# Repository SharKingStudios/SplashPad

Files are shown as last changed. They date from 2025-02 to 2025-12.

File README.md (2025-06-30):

<p align="center">
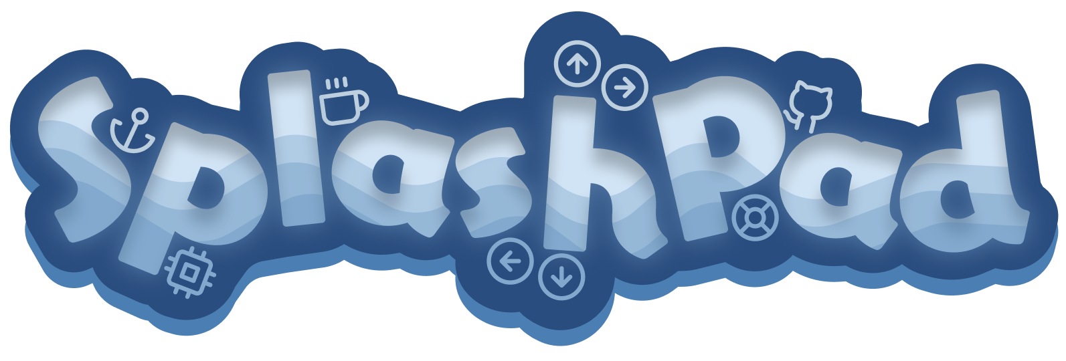
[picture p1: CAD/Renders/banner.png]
Banner
  
</p>

# SplashPad – Because You Deserve More Buttons  

### A Tiny, Glowing, Feature-Packed Macropad for Maximum Efficiency™  

*(Or just a cool way to press "Play" on your music.)*  

---

## Renders 
*Visuals because everyone loves eye candy.*

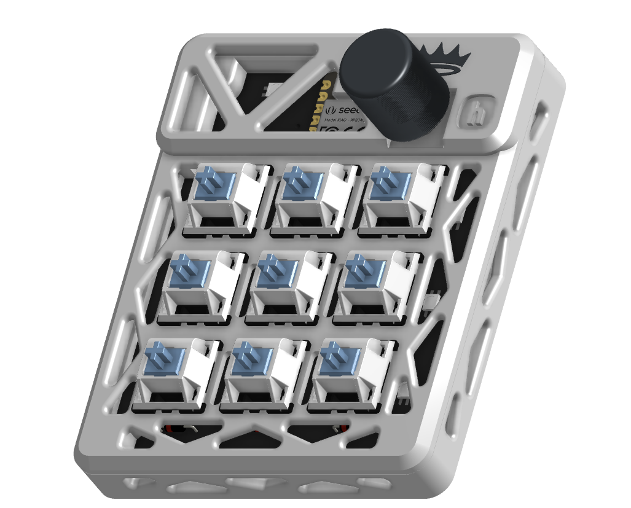
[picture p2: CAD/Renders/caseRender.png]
Case Render

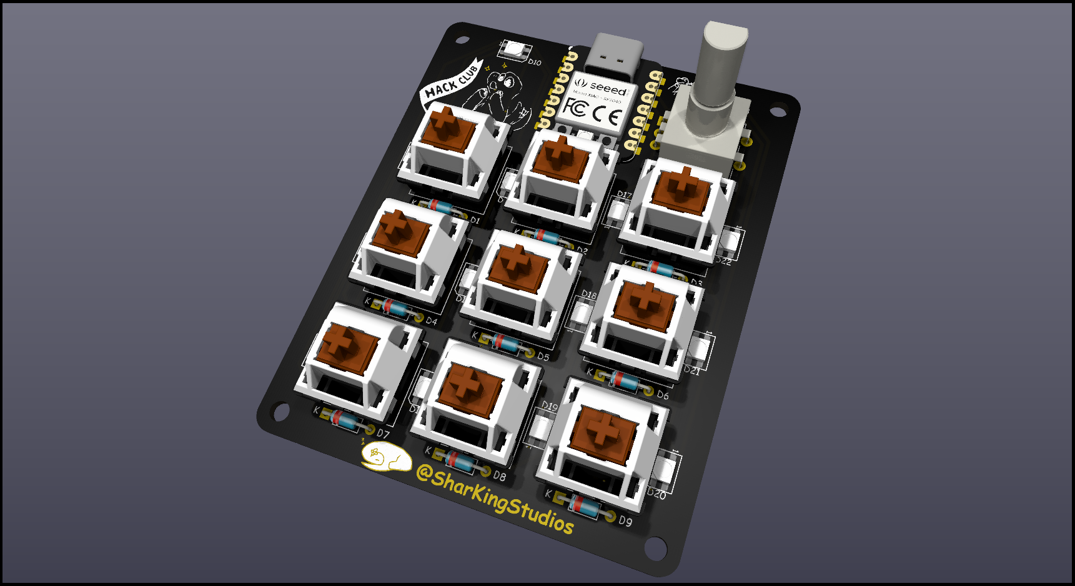
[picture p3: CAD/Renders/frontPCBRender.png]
Front PCB Render

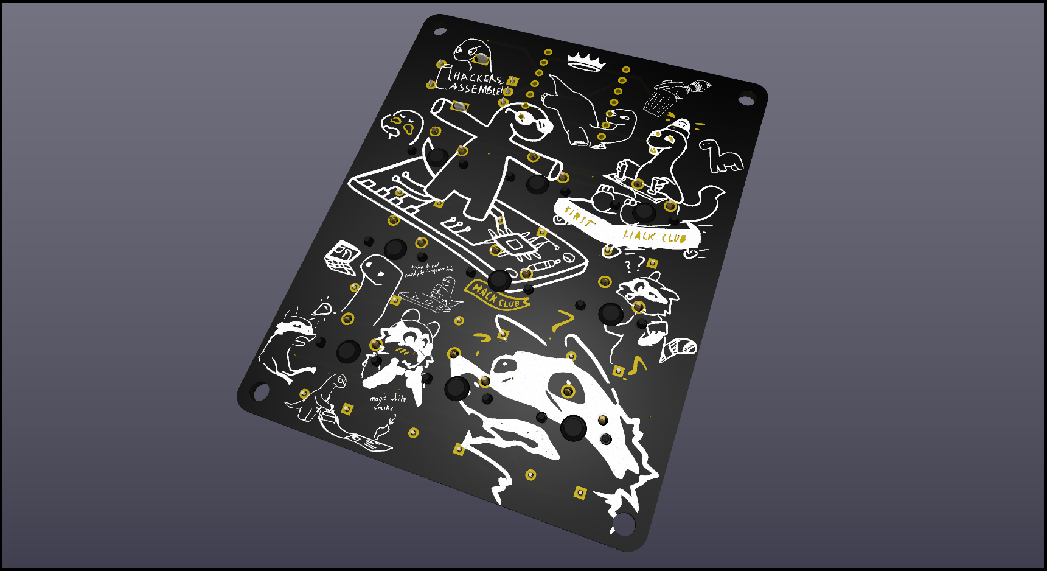
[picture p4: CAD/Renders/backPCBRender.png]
Back PCB Render

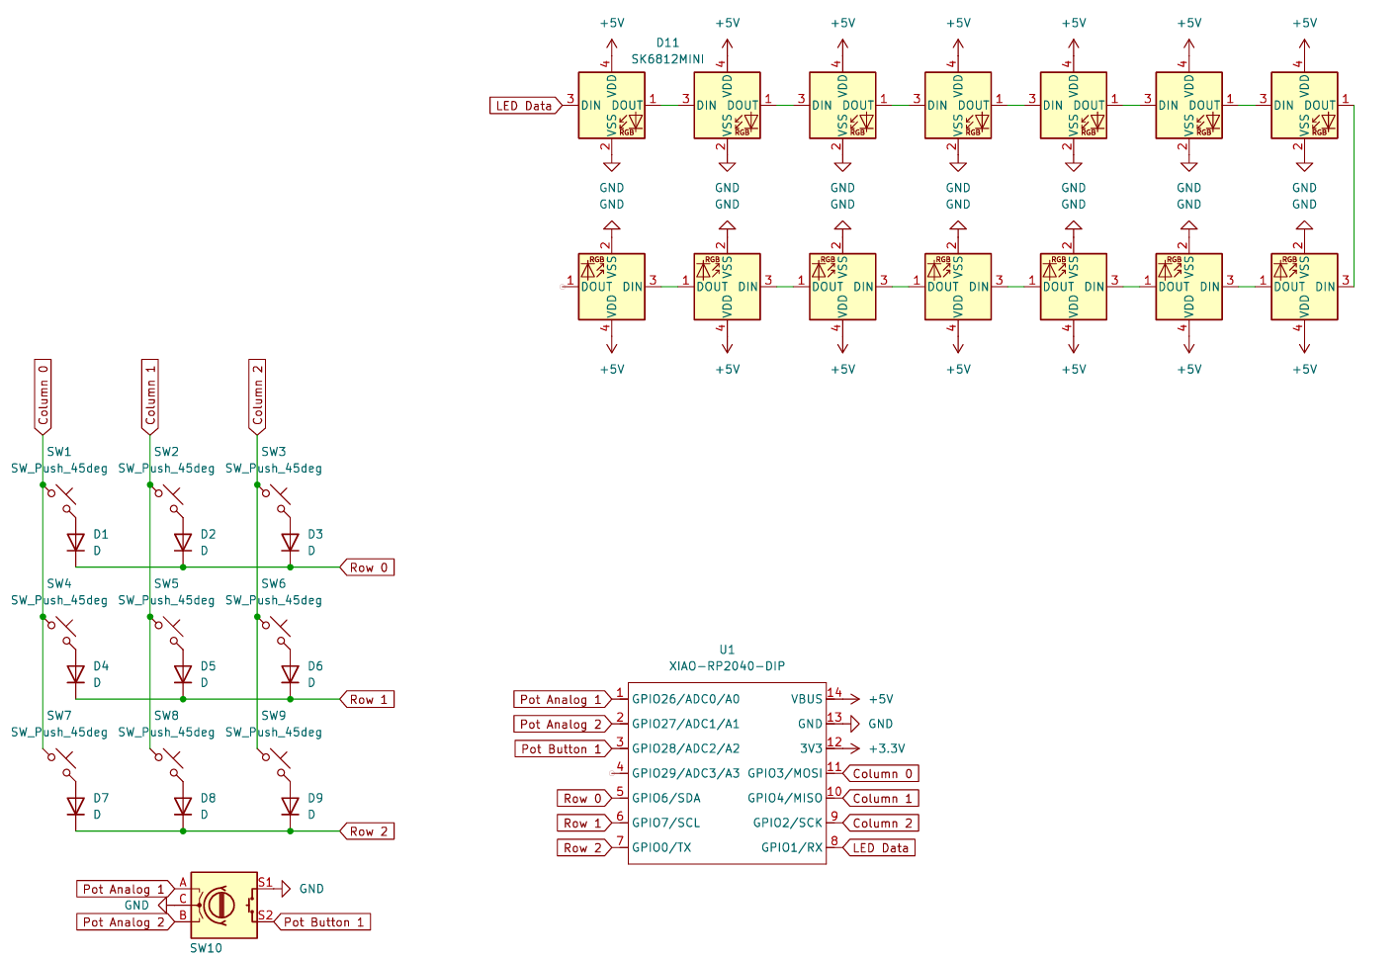
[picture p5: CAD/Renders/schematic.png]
Schematic Picture

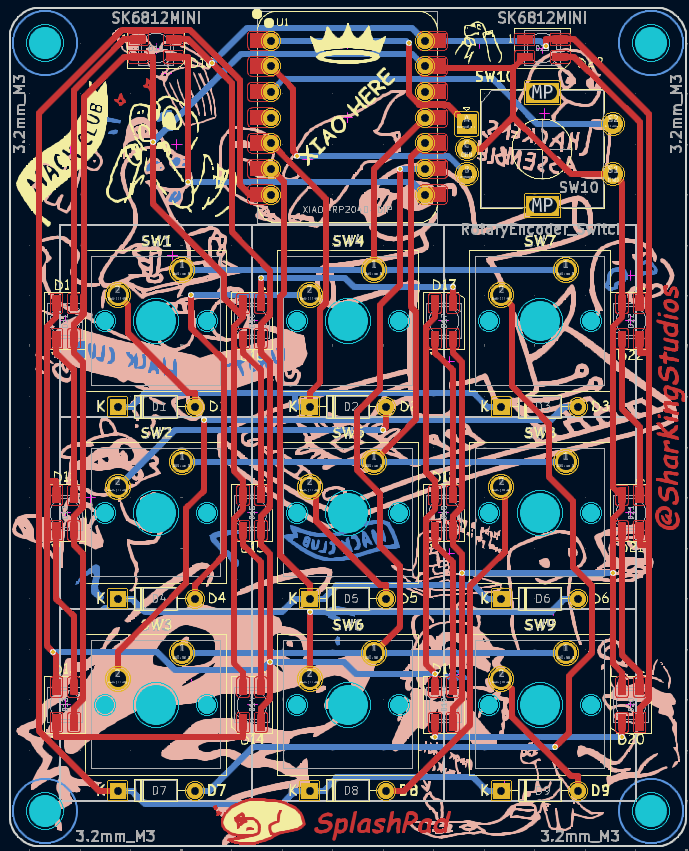
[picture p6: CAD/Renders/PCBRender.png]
PCB Design Picture


---
## BOM
All the bits and pieces needed can be found **[here](/BOM.md)**.

---

## What is this?  
It’s a **custom macropad** built with the **Seeed Studio XIAO RP2040**, **KMK firmware**, and **way too many LEDs**. Whether you’re gaming, editing, coding, or just pressing random buttons for fun, this thing’s got you covered.

### Features:
- **3x3 Matrix** – Nine glorious keys to map to whatever your heart desires.
- **Rotary Encoder** – Twist for volume, scroll, or secret hacker functions.
- **Clickable Encoder Button** – Because sometimes, twisting isn’t enough.
- **14 SK6812 Mini LEDs** – Way too many for a macropad this size. But hey, ✨blinkenlights✨.
- **Multiple LED Modes** – Solid, Rainbow, Wave, and Grid Fade, for when you need that cyberpunk aesthetic.
- **KMK Firmware** – Python-powered and open-source, because we like freedom.

---

## How It Works:
This macropad runs **KMK**, which means you get:
- **Custom Keymaps** – Map macros, media keys, or even full-blown scripts.
- **Dynamic Layers** – More functions per button? Yes, please.
- **LED Control** – Pulsing blue? Rainbow waves? Subtle grid fade? Pick your poison.
- **Rotary Encoder Support** – Spin for volume, brightness, scrolling, or **whatever**.

---

## Default Keymap (For the Lazy):
*(Change it if you want, I'm not your boss.)*

### **3x3 Button Layout:**
| Row | Key 1  | Key 2 | Key 3 |
|---|---|---|---|
| **1** | Rewind | Play/Pause | Fast Forward |
| **2** | Media  | Calculator | Cmd+R (Refresh) |
| **3** | Left | Right | Cmd+L (Lock) |

### **Rotary Encoder:**
- **Left Turn** → Volume Down
- **Right Turn** → Volume Up
- **Press Button** → Cycle LED modes

---

## How to Use:  
1. **Flash KMK** onto your XIAO RP2040. *(If you don’t know how, Google it.)*
2. **Drop `kb.py` and `main.py`** onto your board.
3. **Plug it in.** Watch the lights do their thing.
4. **Press buttons.** Turn the knob. Make magic happen.

---

## LED Modes:
Because a macropad without RGB is just a fancy calculator.

- **Solid Mode** – A slow, pulsing blue (totally not just lazy coding).
- **Rainbow Mode** – Taste the colors.
- **Wave Mode** – Water flow effect because vibes.
- **Grid Fade Mode** – Simulates sunlight through water. Or something poetic like that.

*(Press the encoder button to switch between them.)*

---

## Why?
I built this macropad for [Hackpad](https://hackpad.hackclub.com/)—an awesome Hack Club YSWS project run by [Alex Ren](https://github.com/qcoral). With a the (hopeful) funding provided by the project, I wanted to create something that’s as practical as it is playful. Whether you're coding, gaming, or just jamming to your favorite tunes, this macropad is my way of saying:

#### why settle for ordinary when you can hack something extraordinary?

## The Biggest Challenge:
I wanted to use nice thick wires for my PCB (0.6mm) and routing all of these took quite a bit of effort. I think the time spent was definitely worth it, as the routing looks *awesome*.

---

## Future Plans (Maybe):  
- OLED Screen? 🤔  
- Bluetooth support? (If I hate myself enough to deal with that.)
- More layers? (How many is too many? Asking for a friend.)
- MIDI support? (Why not turn this into a DJ controller?)

---

## Contribute  
Want to make it better? Open a PR, suggest a feature, or just yell at me on GitHub.

---

## Disclaimer  
This project is 100% free, open-source, and powered by **vibes**. If it breaks, explodes, or opens a black hole, **that’s on you.**

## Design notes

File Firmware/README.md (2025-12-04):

# KMK Firmware – SplashPad

### The Brains Behind My Macropad

This folder contains the **KMK firmware** for my **SplashPad**.

---

## What's over here? 
- **`kb.py`** – Defines the hardware setup: key matrix, rotary encoder, LED setup, and pin assignments.
- **`main.py`** – The actual firmware logic: key mappings, rotary encoder functions, LED effects, and main loop.

---

## Default Keymap  
| Row | Key 1  | Key 2 | Key 3 |
|---|---|---|---|
| **1** | Rewind | Play/Pause  | Fast Forward |
| **2** | Media  | Eject Media | Enter |
| **3** | Left | Right | Cmd |

- **Rotary Encoder:**  
  - **Left** → Volume Down
  - **Right** → Volume Up
  - **Press** → Cycle LED Modes

---

## LED Modes  
- **Solid Mode** – A slow pulsing blue glow.
- **Rainbow Mode** – Cycling RGB for that *gamer aesthetic*.
- **Wave Mode** – Water flow effect (because vibes).
- **Grid Fade Mode** – A subtle pulsing effect inspired by sunlight through water.

*(Press the encoder button to switch modes.)*

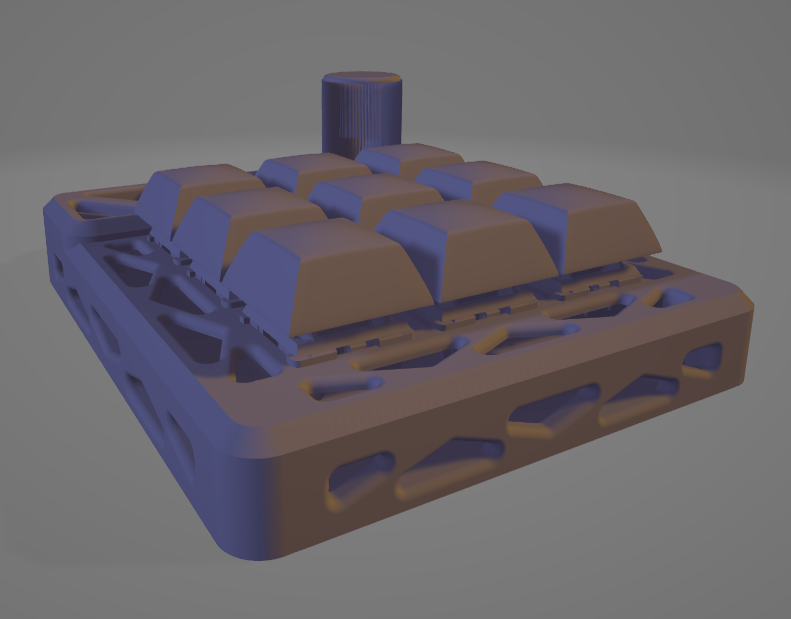
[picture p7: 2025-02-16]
CAD/Renders/darkPurpleRender.png

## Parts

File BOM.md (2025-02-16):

# SplashPad - Bill of Materials

Welcome to the **Bill of Materials (BOM)** – the sacred scroll of **everything** needed for my SplashPad. 

*(Because nothing’s worse than realizing you forgot the screws after your parts arrive.)* 

| **Component** | **Qty** |
|---|---|
| **XIAO RP2040** | 1 |
| **SK6812 Mini LEDs** | 14 |
| **Rotary Encoder** | 1 |
| **Cherry MX Switches** | 9 |
| **PCB** | 1 |
| **Diodes (1N4148)** | 9 |
| **M3x8 Bolt** | 4 |

Others:

| **Component** | **Qty** |
|---|---|
| **1U Keycaps** | 9 |
| **KMK Firmware** | 1 |
| **PCB** | 1 |
| [**Case Top.stl**](/CAD/STL/SplashPad%20Case%20-%20Case%20Top.stl) | 1 |
| [**Case Bottom.stl**](/CAD/STL/SplashPad%20Case%20-%20Case%20Bottom.stl) | 1 |
| **Knob.stl** | 1 |

### Notes:
It would be awesome to have the crown parts printed in black!
I can print the knob.
I am buying the M3x8 Bolts.

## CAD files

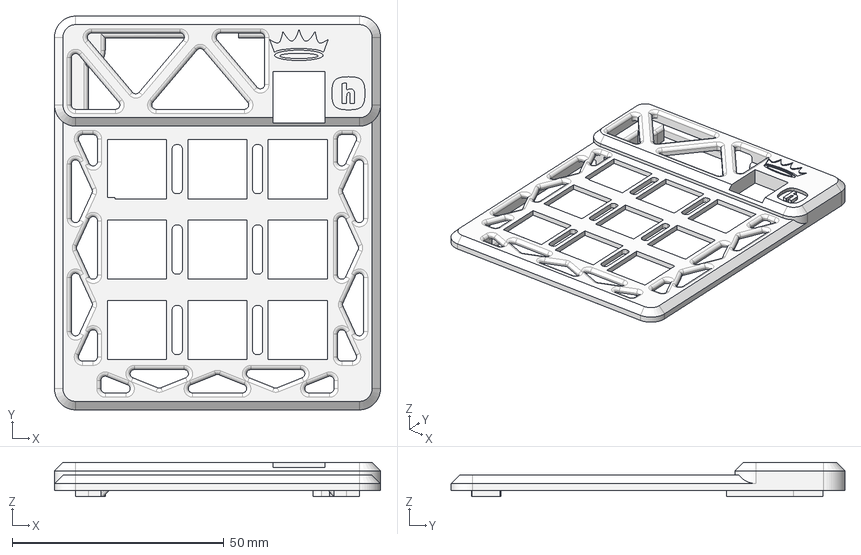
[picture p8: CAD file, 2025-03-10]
CAD/SplashPad Case - Case Top.step
77.0 x 93.0 x 8.09 mm

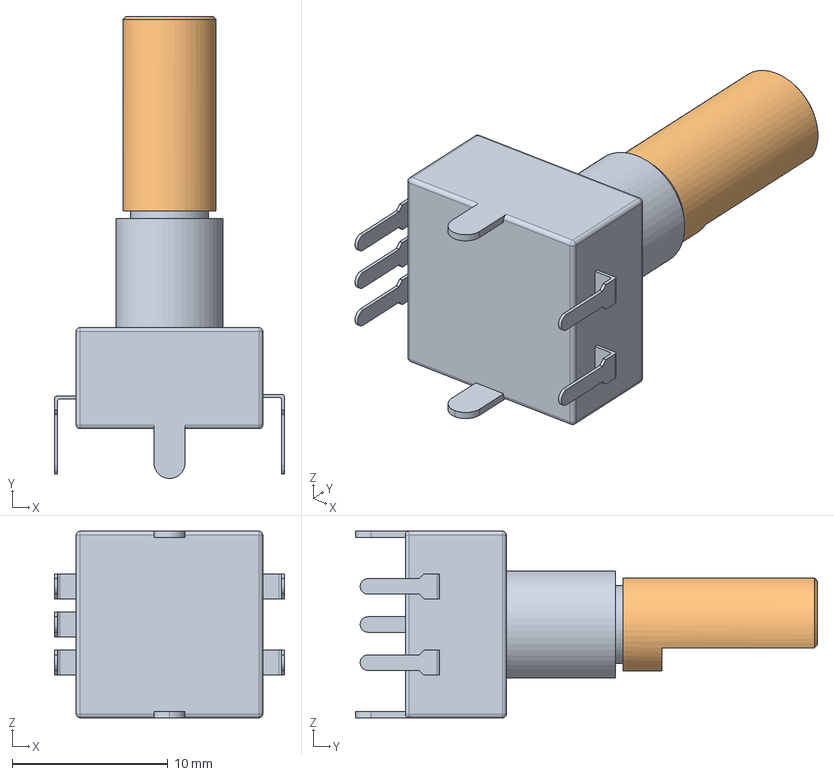
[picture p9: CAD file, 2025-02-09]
PCB/3D Models/RotaryEncoder_Alps_EC11E-Switch_Vertical_H20mm.step
14.8 x 29.7 x 12.0 mm

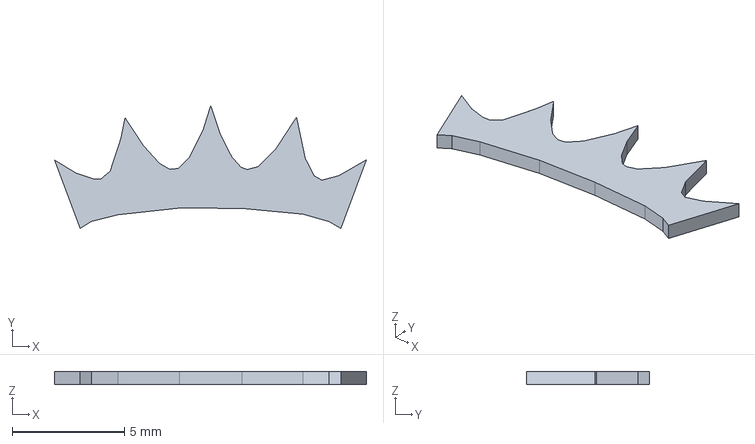
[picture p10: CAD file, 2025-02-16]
Production/SplashPad Case - Crown 2.step
13.9 x 5.47 x 0.6 mm

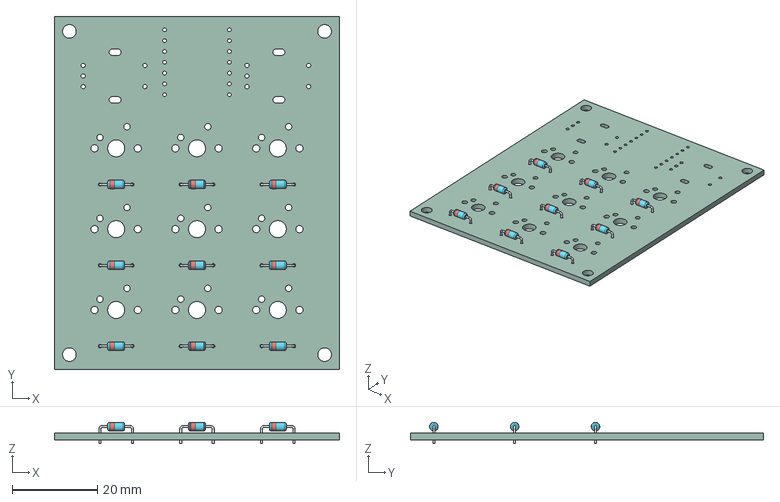
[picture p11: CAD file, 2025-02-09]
SplashPad.step
67.0 x 83.0 x 5.01 mm
D_DO-35_SOD27_P7.62mm_Horizontal x 9
SplashPad_PCB

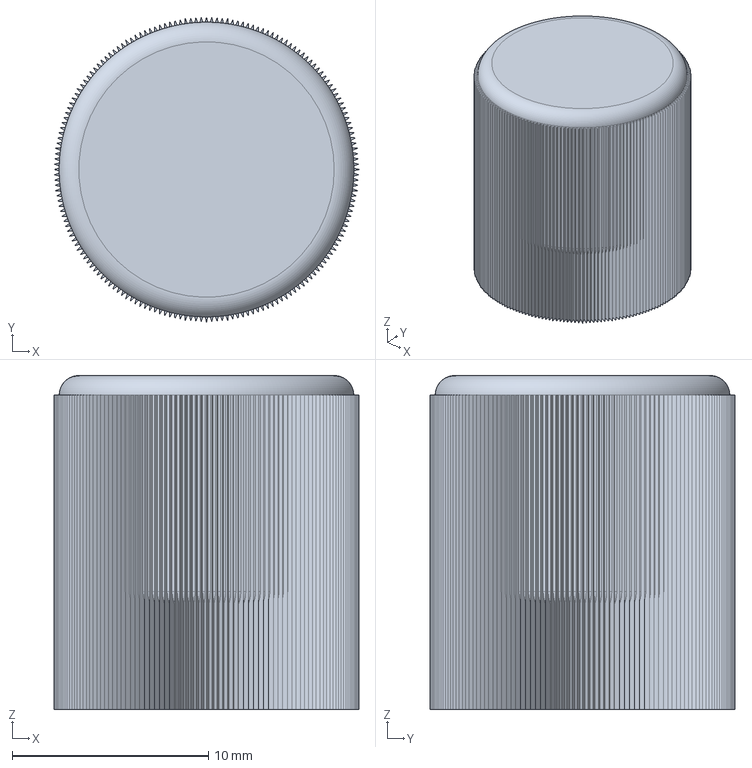
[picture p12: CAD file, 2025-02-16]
CAD/SplashPad Case - Knob.step
15.5 x 15.5 x 17.0 mm

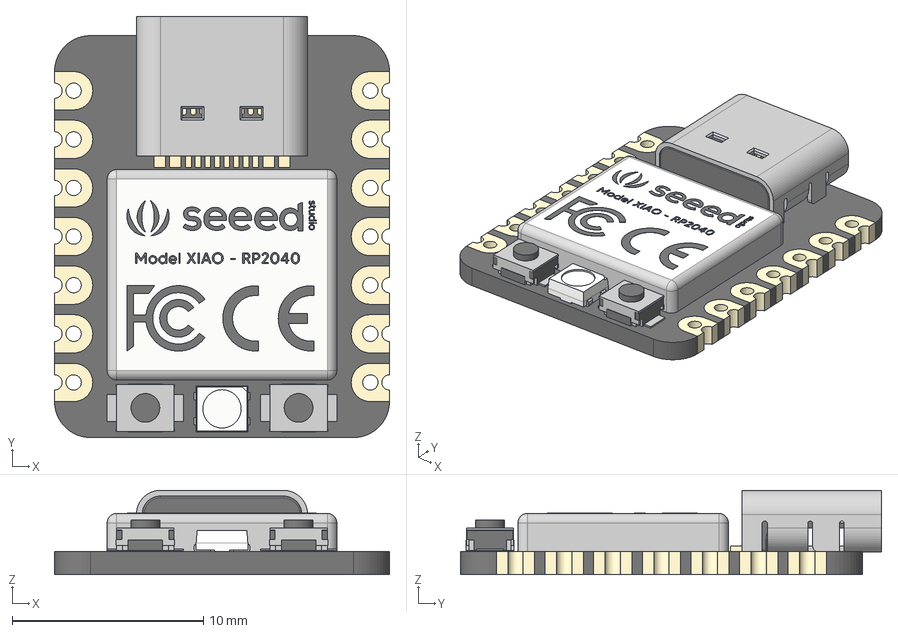
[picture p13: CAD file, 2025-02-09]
PCB/3D Models/Seeed_Studio_XIAO_RP2040_v26.step
17.5 x 22.0 x 4.40 mm
type-c v2
smd_button v3
DOUT
DIN
VSS
VDD
smd_button v3(Mirror)

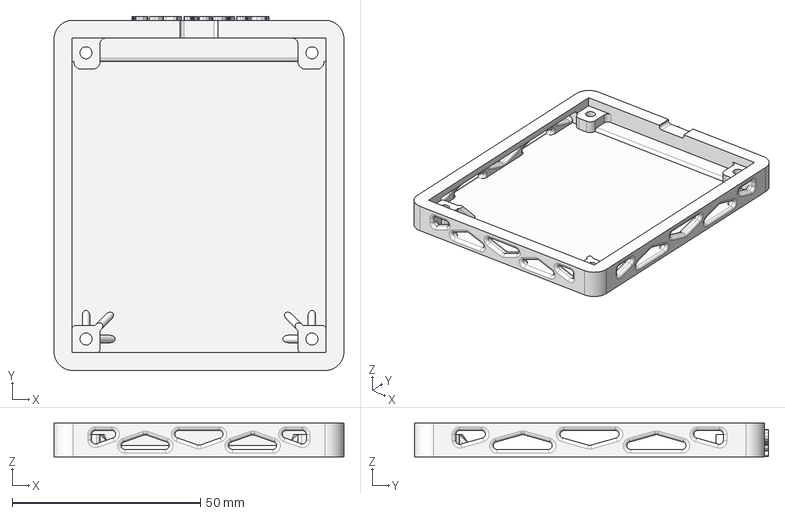
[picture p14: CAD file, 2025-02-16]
CAD/SplashPad Case - Case Bottom.step
77.0 x 94.0 x 9.00 mm

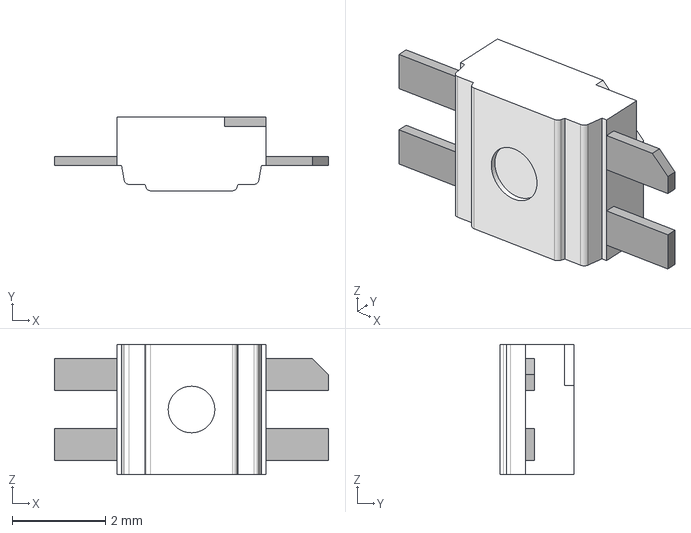
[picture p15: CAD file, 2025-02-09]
PCB/3D Models/SK6812MINI-E.step
5.88 x 1.58 x 2.80 mm

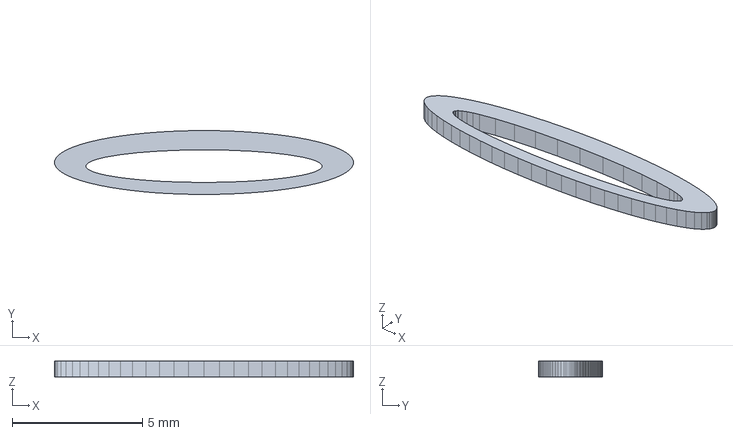
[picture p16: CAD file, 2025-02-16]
Production/SplashPad Case - Crown 1.step
11.5 x 2.45 x 0.6 mm

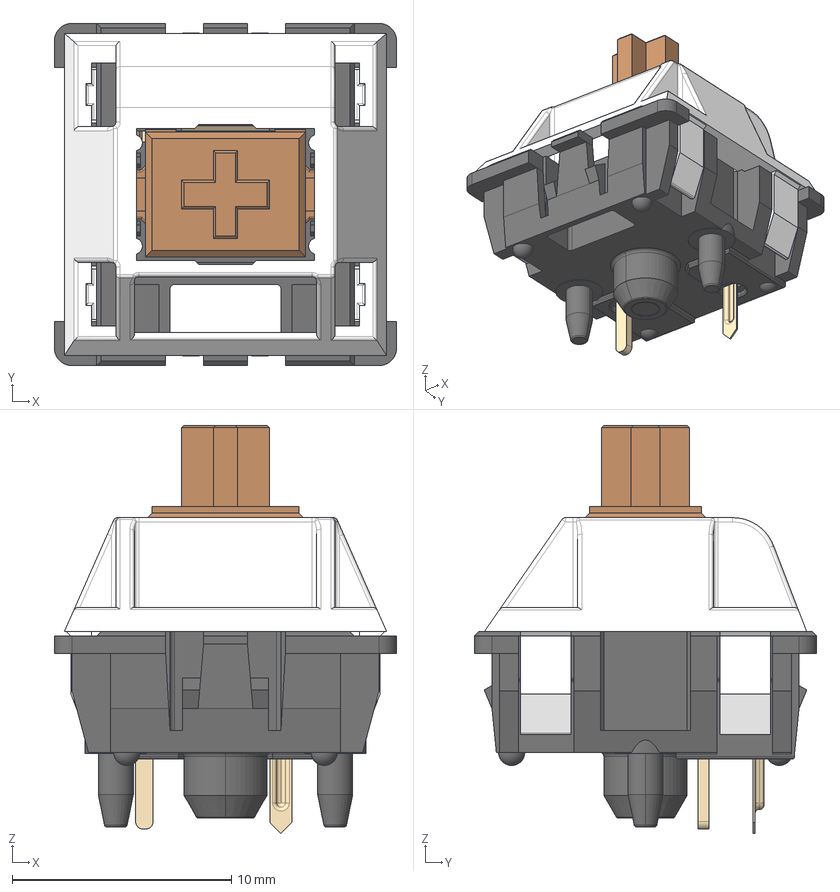
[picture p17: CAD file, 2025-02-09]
PCB/3D Models/MX_Switch.step
15.6 x 15.6 x 18.6 mm

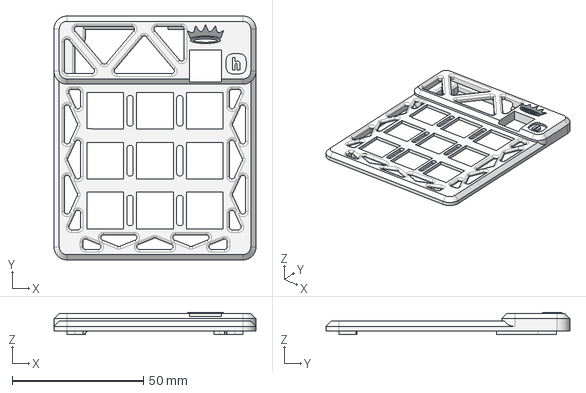
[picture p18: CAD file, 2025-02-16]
Production/SplashPad Case - Case Top (Combined w. Crown).step
77.0 x 93.0 x 8.39 mm

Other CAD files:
Production/SplashPad Case - Case Top.step
CAD/STL/SplashPad Case - Case Top.stl
CAD/STL/SplashPad Case - Crown 1.stl
CAD/STL/SplashPad Case - Crown 2.stl
CAD/STL/SplashPad Case - Knob.stl

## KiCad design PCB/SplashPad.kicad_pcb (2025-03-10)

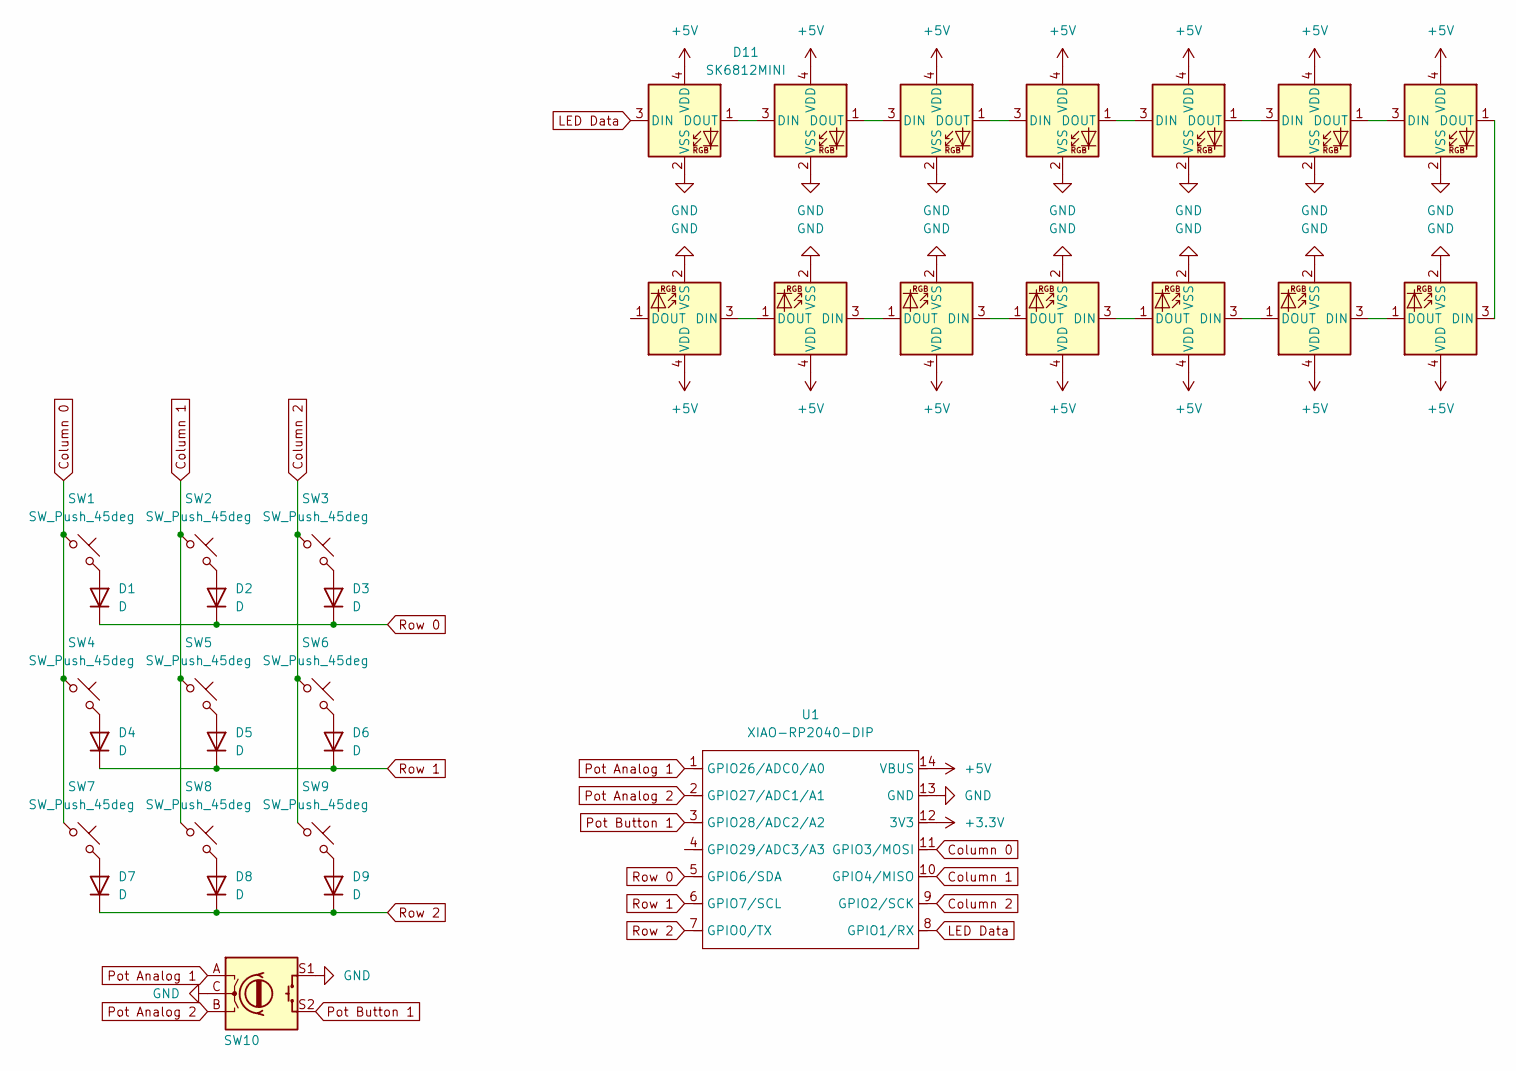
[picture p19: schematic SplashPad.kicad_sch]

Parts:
D1, D2, D3, D4, D5, D6, D7, D8, D9: D; D_DO-35_SOD27_P7.62mm_Horizontal
D10, D11, D12, D13, D14, D15, D16, D17, D18, D19, D20, D21, D22, D23: SK6812MINI; LED_SK6812MINI_PLCC4_3.5x3.5mm_P1.75mm
SW1, SW2, SW3, SW4, SW5, SW6, SW7, SW8, SW9: SW_Push_45deg; SW_Cherry_MX_1.00u_PCB
SW10: RotaryEncoder_Switch; RotaryEncoder_Alps_EC11E-Switch_Vertical_H20mm
U1: XIAO-RP2040-DIP

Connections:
+3.3V: U1.12 (3V3)
+5V: D10.4 (VDD), D11.4 (VDD), D12.4 (VDD), D13.4 (VDD), D14.4 (VDD), D15.4 (VDD), D16.4 (VDD), D17.4 (VDD), D18.4 (VDD), D19.4 (VDD), D20.4 (VDD), D21.4 (VDD), D22.4 (VDD), D23.4 (VDD), U1.14 (VBUS)
Column 0: SW1.1, SW4.1, SW7.1, U1.11 (GPIO3/MOSI)
Column 1: SW2.1, SW5.1, SW8.1, U1.10 (GPIO4/MISO)
Column 2: SW3.1, SW6.1, SW9.1, U1.9 (GPIO2/SCK)
GND: D10.2 (VSS), D11.2 (VSS), D12.2 (VSS), D13.2 (VSS), D14.2 (VSS), D15.2 (VSS), D16.2 (VSS), D17.2 (VSS), D18.2 (VSS), D19.2 (VSS), D20.2 (VSS), D21.2 (VSS), D22.2 (VSS), D23.2 (VSS), SW10.C, SW10.S1, U1.13 (GND)
LED Data: D10.3 (DIN), U1.8 (GPIO1/RX)
unnamed: D1.2 (A), SW1.2
unnamed: D2.2 (A), SW2.2
unnamed: D3.2 (A), SW3.2
unnamed: D4.2 (A), SW4.2
unnamed: D5.2 (A), SW5.2
unnamed: D6.2 (A), SW6.2
unnamed: D7.2 (A), SW7.2
unnamed: D8.2 (A), SW8.2
unnamed: D9.2 (A), SW9.2
unnamed: D10.1 (DOUT), D11.3 (DIN)
unnamed: D11.1 (DOUT), D12.3 (DIN)
unnamed: D12.1 (DOUT), D13.3 (DIN)
unnamed: D13.1 (DOUT), D14.3 (DIN)
unnamed: D14.1 (DOUT), D15.3 (DIN)
unnamed: D15.1 (DOUT), D16.3 (DIN)
unnamed: D16.1 (DOUT), D17.3 (DIN)
unnamed: D17.1 (DOUT), D18.3 (DIN)
unnamed: D18.1 (DOUT), D19.3 (DIN)
unnamed: D19.1 (DOUT), D20.3 (DIN)
unnamed: D20.1 (DOUT), D21.3 (DIN)
unnamed: D21.1 (DOUT), D22.3 (DIN)
unnamed: D22.1 (DOUT), D23.3 (DIN)
Pot Analog 1: SW10.A, U1.1 (GPIO26/ADC0/A0)
Pot Analog 2: SW10.B, U1.2 (GPIO27/ADC1/A1)
Pot Button 1: SW10.S2, U1.3 (GPIO28/ADC2/A2)
Row 0: D1.1 (K), D2.1 (K), D3.1 (K), U1.5 (GPIO6/SDA)
Row 1: D4.1 (K), D5.1 (K), D6.1 (K), U1.6 (GPIO7/SCL)
Row 2: D7.1 (K), D8.1 (K), D9.1 (K), U1.7 (GPIO0/TX)

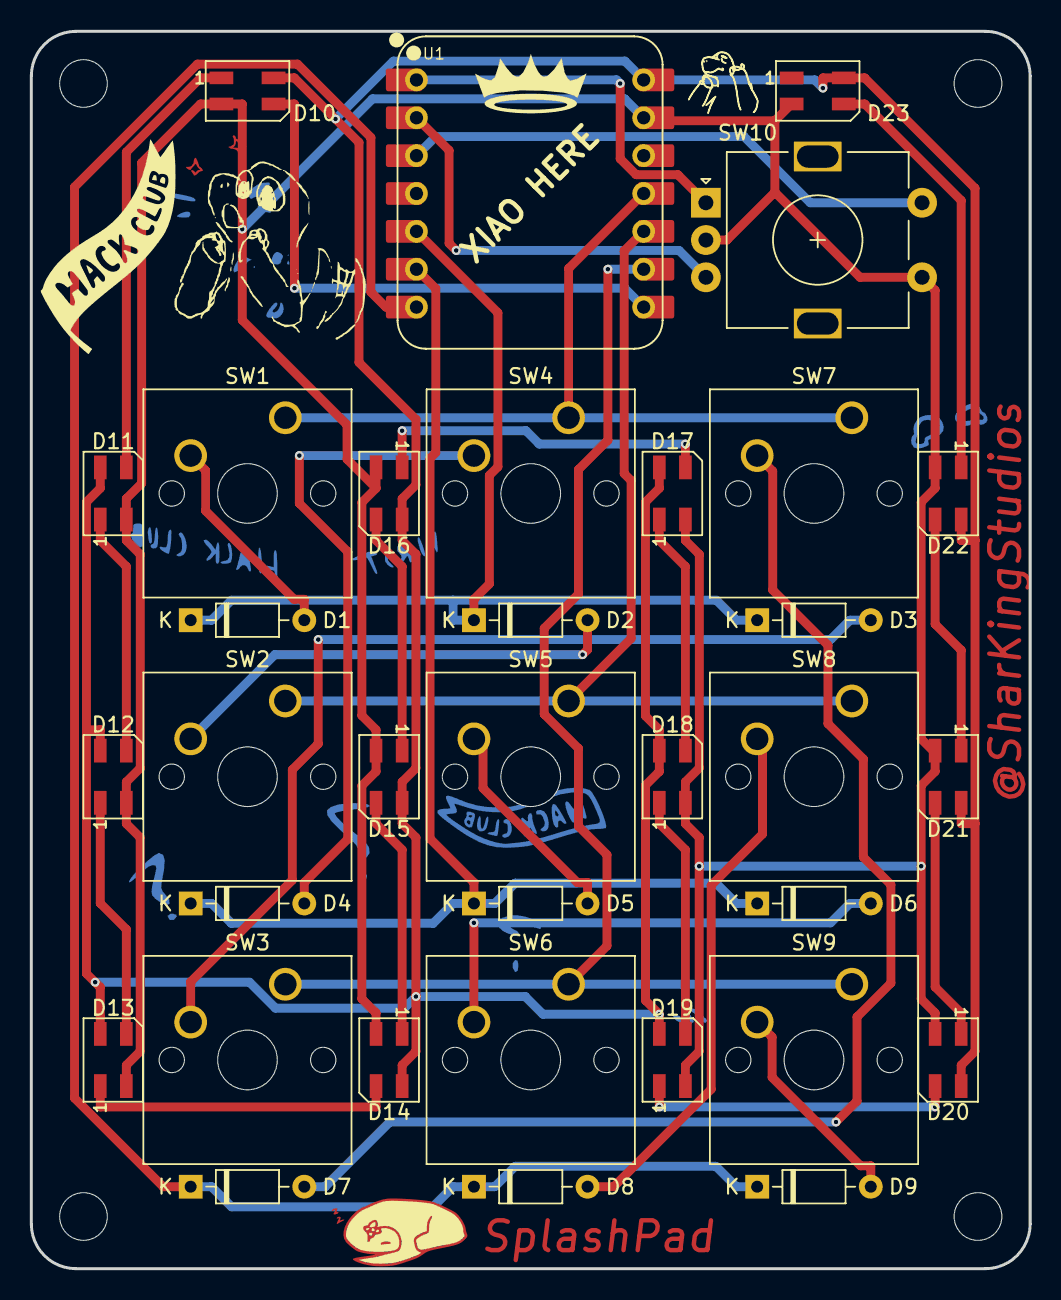
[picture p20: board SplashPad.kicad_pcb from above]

Board: 2 copper layers, 67.0 x 83.0 mm, 38 parts (0 on the bottom side), 34 nets.

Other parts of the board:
HOLE1, HOLE2, HOLE3, HOLE4: 3.2mm_M3; MountingHole_3.2mm_M3

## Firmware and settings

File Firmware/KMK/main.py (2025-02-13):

import board
import time
import math
import digitalio
from kmk.kmk_keyboard import KMKKeyboard
from kmk.keys import KC
from kmk.modules.layers import Layers
from kmk.modules.rotary_encoder import RotaryEncoderHandler

# Initialize keyboard
keyboard = KMKKeyboard()

# Define layers module
layers = Layers()
keyboard.modules.append(layers)

# Define rotary encoder module
encoder_handler = RotaryEncoderHandler()
keyboard.modules.append(encoder_handler)

# Define keymap for 3x3 matrix
keyboard.keymap = [
    [KC.MRWD, KC.MPLY, KC.MFFD],  # Top row
    [KC.MSEL, KC.CALC, KC.LGUI(KC.R)],  # Middle row
    [KC.LEFT, KC.RIGHT, KC.LGUI(KC.L)],  # Bottom row
]

# Assign rotary encoder actions
encoder_handler.pins = (board.GP26, board.GP27)
encoder_handler.divisor = 4
encoder_handler.map = [KC.VOLD, KC.VOLU]  # Rotate Left = Volume Down, Rotate Right = Volume Up

# Define rotary encoder button
encoder_button = digitalio.DigitalInOut(board.GP28)
encoder_button.switch_to_input(pull=digitalio.Pull.UP)

# LED Mode Variables
led_modes = ["Solid", "Rainbow", "Wave", "Grid Fade"]
current_mode = 0

# Function to update LED effects
def update_leds():
    keyboard.leds.fill((0, 0, 0, 0))  # Clear LEDs

    if led_modes[current_mode] == "Solid":  # Actually a slow pulsing blue lol
        t = time.monotonic() * 1.5  # Anim speed
        for i, (x, y) in enumerate(keyboard.led_positions):
            wave = int((math.sin(t + x * 0.5 + y * 0.5) + 1) * 127)
            keyboard.leds[i] = (0, 0, wave, wave // 2)
    elif led_modes[current_mode] == "Rainbow":
        for i, (x, y) in enumerate(keyboard.led_positions):
            keyboard.leds[i] = (i * 18, 255 - i * 18, 0, 0)  # Rainbow effect
    elif led_modes[current_mode] == "Wave":  # Water flow effect with sin motion
        t = time.monotonic() * 2  # Anim speed
        for i, (x, y) in enumerate(keyboard.led_positions):
            wave_intensity = int((math.sin(t + (x * 0.8) + (y * 0.5)) + 1) * 127)
            keyboard.leds[i] = (0, wave_intensity // 2, wave_intensity, 0)
    elif led_modes[current_mode] == "Grid Fade": # Gentle pulsing effect, I was trying to mimic sunlight through water
        t = time.monotonic() * 1.2  # Anim speed
        for i, (x, y) in enumerate(keyboard.led_positions):
            brightness = int((math.sin(t + x + y) + 1) * 80)
            keyboard.leds[i] = (0, brightness // 2, brightness, 0)

    keyboard.leds.show()

# Main Loop for LED Mode Cycling
def handle_led_modes():
    global current_mode
    if not encoder_button.value:  # Button pressed
        time.sleep(0.2)  # Debounce
        current_mode = (current_mode + 1) % len(led_modes)  # Cycle modes
        update_leds()

if __name__ == "__main__":
    while True:
        keyboard.go()
        handle_led_modes()
        update_leds()
        time.sleep(0.1)

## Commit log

2025-02-08 "minor changes"
    relearned KiCAD lol
    [SplashPad.kicad_pcb, SplashPad.kicad_sch]
2025-02-09 fine tuning
    [MX_Switch.step, SK6812MINI-E.step, Seeed_Studio_XIAO_RP2040_v26.step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]
2025-02-09 The Fun Part
    [SplashPad.kicad_pcb]
2025-02-09 encoder fix
    [RotaryEncoder_Alps_EC11E-Switch_Vertical_H20mm.step, SplashPad.kicad_pcb, SplashPad.kicad_sch]
2025-02-09 trace fix
    [SplashPad.kicad_pcb]
2025-02-13 Awesome Silkscreen Art!
    [SplashPad.kicad_pcb]
2025-02-13 KMK Firmware
    Surprisingly easy
    [SplashPad.kicad_pcb]
2025-02-16 The submission
    Pretty sure this is it.
    :)
    [MX_Switch.step, RotaryEncoder_Alps_EC11E-Switch_Vertical_H20mm.step, SK6812MINI-E.step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]
2025-02-16 Final Updates
    This is the last one I swear
    [SplashPad Case - Case Top.step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]
2025-03-10 LED Voltage Fix
    I thought they worked at 3.3v oopsies
    I also had the encoder wired wrong and fixed that.
    [SplashPad.kicad_pcb, SplashPad.kicad_sch]
